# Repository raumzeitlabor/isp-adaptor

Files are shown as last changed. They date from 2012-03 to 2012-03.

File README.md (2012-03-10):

This is a simple ISP adapter, which can be used to convert from 10-pin ISP to 6-pin ISP connectors and features a pin header for manual connections.

If you are etching the PCB yourself, you can either etch a double-side PCB or simply glue the transparent foil on the PCB to have pin indications.

Schematic and board are made in Eagle 6.1.0.

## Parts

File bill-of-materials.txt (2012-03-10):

Amount	Description						Reichelt OrderNo.	Price
1	Pin Header, 8-pin, Pitch Spacing: 0.1" (2.54mm)		SL 1X36G 2,54		0.14 €
1	2x3 Connection Header					WSL 6G			0.16 €
1	2x5 Connection Header					WSL 10G			0.08 €

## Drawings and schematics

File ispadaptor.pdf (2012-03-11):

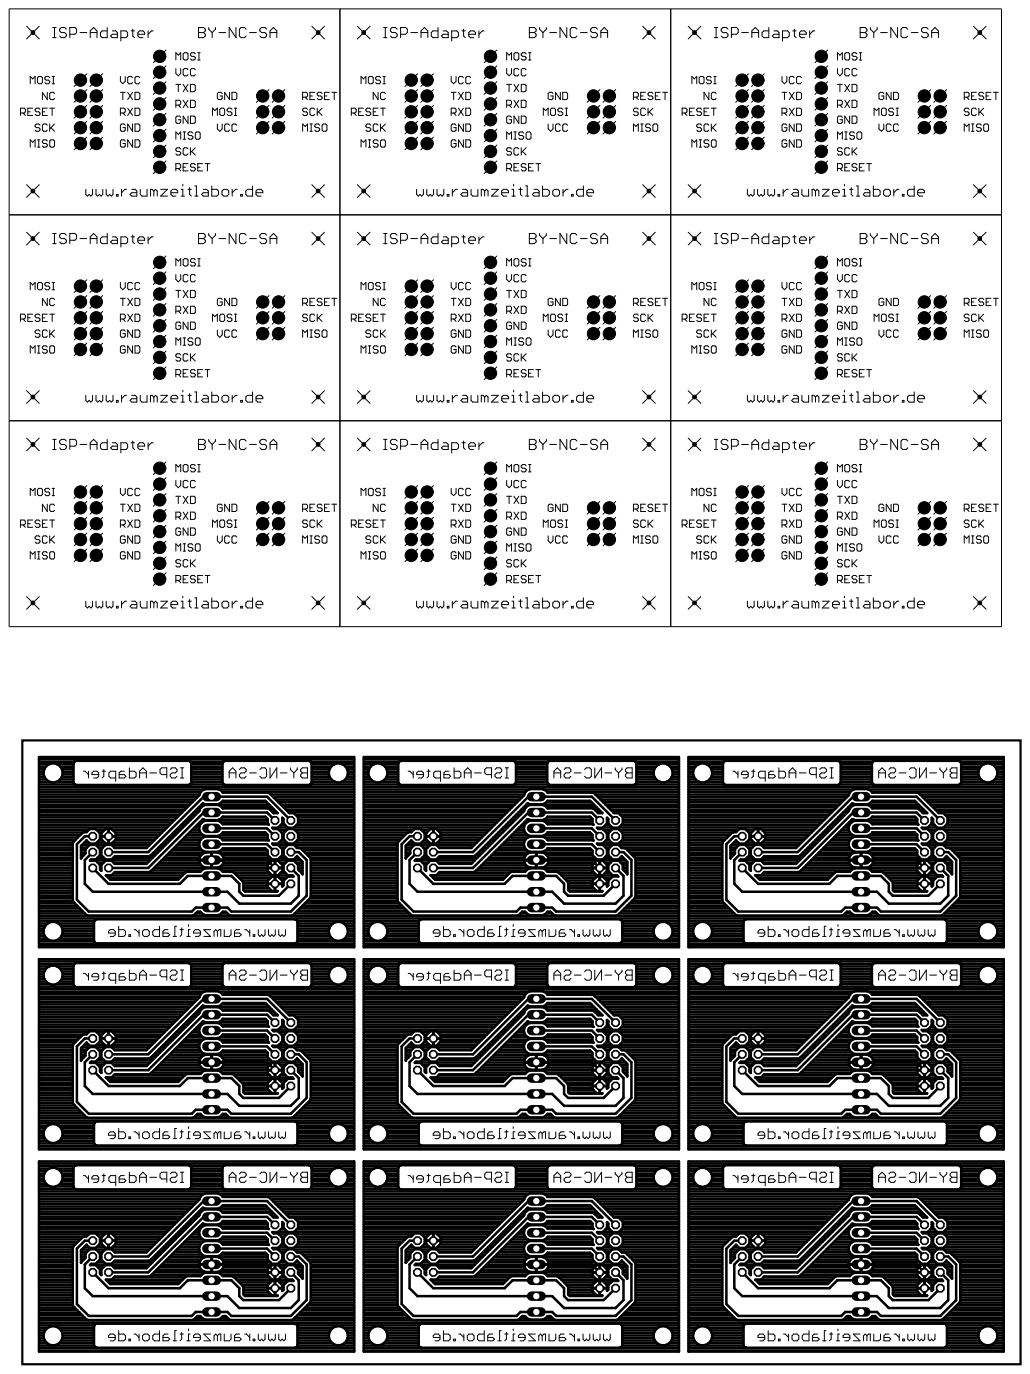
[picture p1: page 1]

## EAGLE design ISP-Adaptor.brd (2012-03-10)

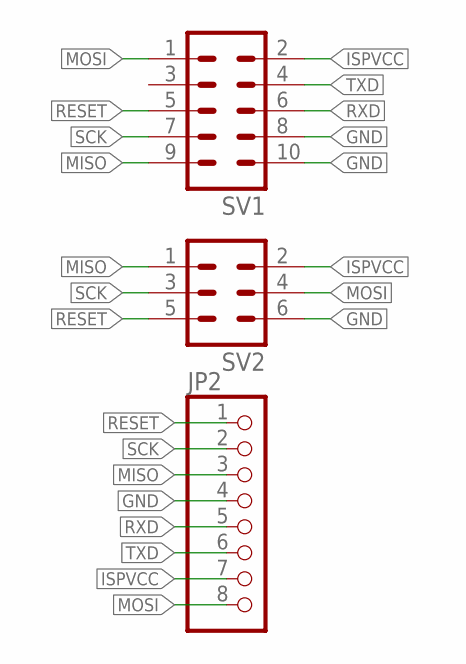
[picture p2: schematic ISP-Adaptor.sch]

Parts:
JP2: PINHD-1X8; 1X08
SV1: ML10
SV2: ML6

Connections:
GND: JP2.4, SV1.8, SV1.10, SV2.6
ISPVCC: JP2.7, SV1.2, SV2.2
MISO: JP2.3, SV1.9, SV2.1
MOSI: JP2.8, SV1.1, SV2.4
RESET: JP2.1, SV1.5, SV2.5
RXD: JP2.5, SV1.6
SCK: JP2.2, SV1.7, SV2.3
TXD: JP2.6, SV1.4

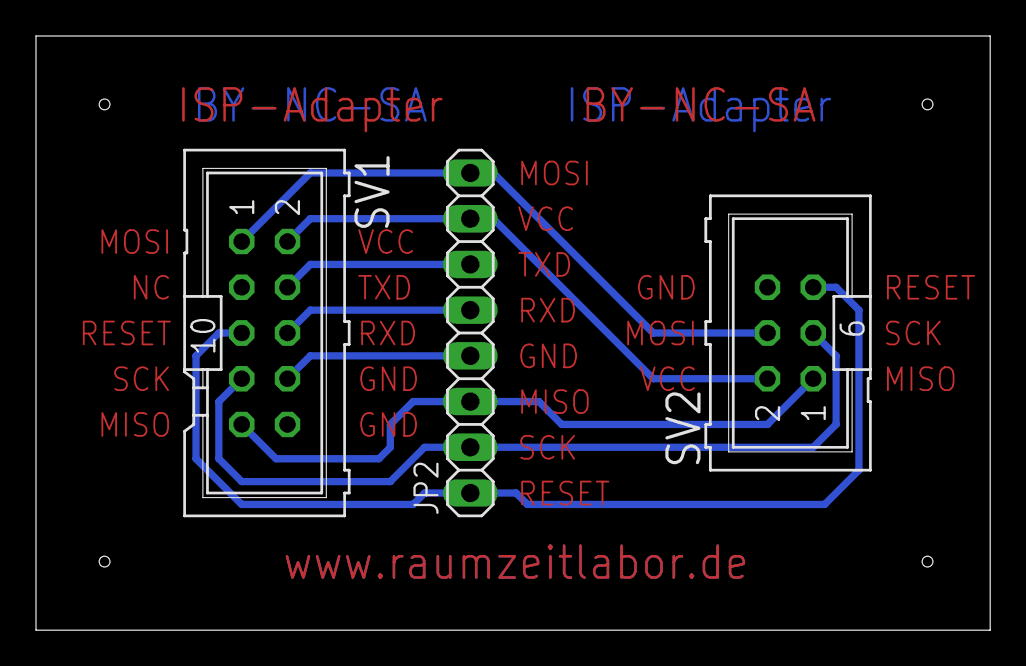
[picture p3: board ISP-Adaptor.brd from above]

Board: 2 copper layers, 53.0 x 33.0 mm, 3 parts (0 on the bottom side), 8 nets.

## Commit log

2012-03-10 Added BOM
2012-03-10 Fixed mirroring in the PCB layout
    [ISP-Adaptor.brd]
